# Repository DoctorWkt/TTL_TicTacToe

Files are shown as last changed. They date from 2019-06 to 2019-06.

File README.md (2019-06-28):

# TTL_TicTacToe

I've seen several circuits for two-player tic-tac-toe games on the Internet,
but I thought I'd try to design one with these constraints:

 + done with TTL components only, no CPU
 + minimum number of chips
 + not two player: human versus the board, board makes optimal moves

This is the repository for my result. The circuit uses flip-flops to
register both the human and the board's moves. The board has a register
which holds the current state of the board's moves. The board state and
the user's moves are combined to access a ROM to look up the next board move
and any tie or win result.
An [overview of the design](design_notes.md) is available. Here's
a [video](https://www.youtube.com/watch?v=WPPjL46z-Ag) of the board in action.

There are several versions of the design.

## Logisim Version

I built this [Logisim version](ttt_wkt.circ) in preparation for
designing the real circuit with TTL components. If you haven't used
[Logisim](http://www.cburch.com/logisim/) before, open up the _*.circ_
file. Now start the clock with a control-K (or use
_Simulate -> Ticks Enabled_). Now that the circuit is running, click on
the brown finger icon (the poke tool) at the top-left so that you can
press the game buttons.

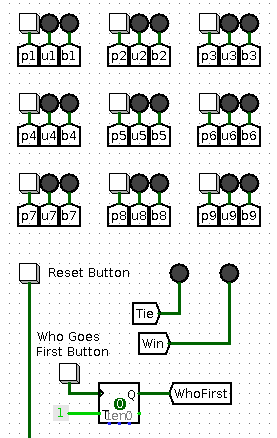
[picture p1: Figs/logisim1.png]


Over on the right you will see a 3x3 grid. The white squares are the
pushbuttons to make a move. Next to each button is a red LED to register
the user's move and a blue LED for the board's moves.

Below this grid there is a Reset button and a "Who Goes First" button.
Press the "Who Goes First" button to toggle between the user moving
first and the board moving first. Then press the Reset button to clear
the board.

Now press the user moves buttons to make your moves. Immediately after
each move, the board will make a move. When a tie occurs, the Tie LED
will light up. When the board wins, the Win LED will light up.

Over on the left are the nine JK flip-flops to record the user's moves,
and the nine JK flip-flops to record the board's moves. Below that is
the ROM which generates a 4-bit value which is the new board's move.
The 4-bit board move goes into the 4:16 demultiplexer to generate the nine
lines which go to the nine JK flip-flops to record the board's moves.
Two of the 16 possible moves are used to indicate a tie or a board win.

The ROM also generates the next state of the board's moves. This is
recorded into a 4-bit register. See the [design notes](design_notes.md)
for details of the state number.

The circuit should come with the latest version of the ROM image. If you
ever regenerate the _ttt.rom_ file, here is how to load it into the circuit.
Right-click on the ROM device in the circuit and choose *Load image* and
choose the _ttl.rom_ file to load.

## Kicad Schematic

In the _Schematic/_ folder you will find a
[Kicad schematic](Schematic/schematic.pdf) for the circuit. This uses:

 + nine 74HC107 dual JK flip flops. Each one holds both the user and board
   move for one position on the board
 + one 28C256 32Kx8 EEPROM to look up the next board move. We only use
   8K of the space in the EEPROM.
 + one 74HC154 4:16 demultiplexer
 + one 75HC161 register to hold the board state number
 + one 555 to generate the clock signal
 + various LEDs to show the moves, and other sundry components.

I've also designed a [PCB](Figs/pcb2.jpg) to hold all the components.
The design has separate LEDs for user and board moves, but I've chosen to use
bi-colour LEDs so that there is a single physical LED for each board position:
green for the user, red for the board, off when empty.

## Generating the 28C256 EEPROM Contents

At the Linux command-line, run the command:

```
make
```

This will use the _gen_moves.pl_ script to generate the user-first moves file
_umoves_, and the board-first moves file _bmoves_. These are then parsed by
the _parse_moves.pl_ script to create the _ttt.rom_ file used by Logisim.

Finally, the _hex2bin_ script takes the _ttt.rom_ file, which is hex-encoded,
and converts it to the binary file _28C256.bin_ which can be burned to the
EEPROM.

If you have a MiniPro EEPROM burner and the _minipro_ command installed,

```
make write
```

will burn the _28C256.bin_ to a 28C256 chip with the MiniPro burner.

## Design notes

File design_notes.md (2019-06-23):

# Design Notes for the TTT Tic Tac Toe Circuit

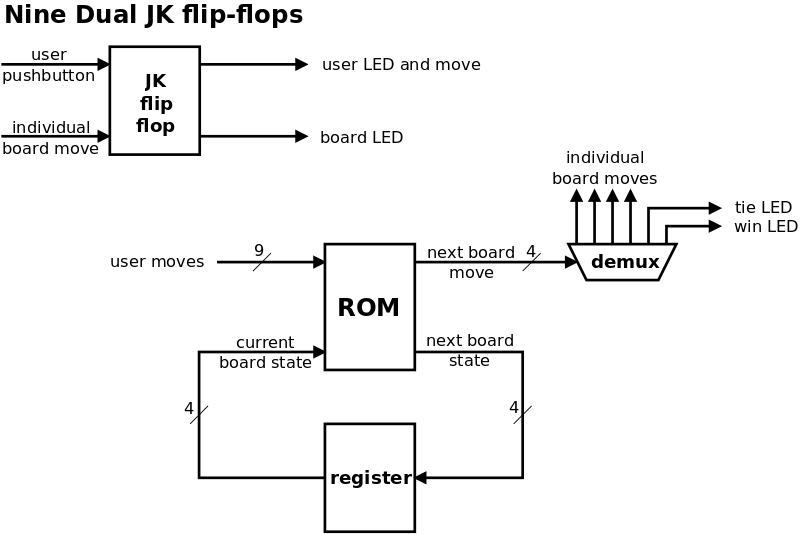
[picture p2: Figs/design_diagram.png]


The state of each position on the board is stored in nine dual JK flip-flops.
The user makes a move by pressing a pushbutton which is recorded in one
flip-flop. Any move made by the board is recorded in a second flip-flop.
This allows two different LEDs to be lit up: green for a user move and red
for a board move at each position. Two flip-flops also allows the board's
move as input to the user flip-flop; this prevents the user from making a
move that the board already has made.

The nine "user move" outputs provide nine bits of address into the ROM.
Four other address bits are provided by a 4-bit register. This records
a "state number" which identifies what set of "board moves" have been
made.

The ROM has 13 bits of input and 8 bits of output. Thus, it can be an 8Kx8
EEPROM. The 13-bit ROM address is used to look up the 8-bit result. Four of the
result bits are the board's next move:

 + 0 means "no move" and is used when waiting for the user to make a move
 + 1 to 9 is a legitimate next move by the board
 + 14 indicates a tie
 + 15 indicates a win by the board

This 4-bit move value goes into the 4:16 demultiplexer to produce the nine
lines that go to the nine flip-flops for the board's move. Two of the
demultiplexer lines, representing 14 and 15, go to the tie LED and board
win LED respectively.

The other four bits of the ROM result are the state number for the new
"board moves". This is recorded into the 4-bit register.

I was originally sending to the ROM nine bits of the user's moves from the user
flip-flops, and  nine bits of the board's moves from the board flip-flops.
This required a ROM with 18 bits of input, i.e. a 256Kx8 ROM. These are not
easily available.

As it turns out, for any 9-bit pattern which is the set of moves that the
user has made, there is only a handful of "board move" situations where
the user could have made this move. Therefore, these situations can be
encoded into a "state number". A state number and the 9-bit "user moves"
pattern is enough to look up the next move the board should play.

There are actually several hundred "board move" situations; I needed
to encode these into 4 bits as I was already outputting 4 bits for the
board's move. Thus, the 4-bit state number is actually a hash value;
several "board move" situations hash down to the same state number.

The constraints on choosing a state number are these:

 + a "board move" situation must always be represented by the same state number
 + any 9-bit "user moves" pattern can be associated with several
   "board move" situations. Each one must be represented with a different
   state number, so as to produce a unique ROM address

Luckily, there are a set of state numbers that satisfy these constraints.
My [parse_moves.pl](parse_moves.pl) script generates these state numbers
and the contents of the ROM.

All of the above has to be implemented with real 7400-style devices.
For the real circuit, I will use these devices:

```
28C256          A 32Kx8 EEPROM, of which we only need 8Kx8. 13 bits of
                input, 8 bits of output. 9 bits of inputs are the user's
                moves so far. 4 bits of input are the current board state
                as stored in the 74HC161 register. 4 output bits represent
                the board move (1 to 9). The other 4 output bits represent
                the next board state to put into the register. A move
                numbered 14 is a tie; a move numbered 15 is a board win.
74HC154         A 4-line to 16-line decoder/demultiplexer, inverting outputs.
                The 4-bit board move output from the ROM is wired to this.
                9 outputs are wired to the flip-flips for the X moves.
74HC161         A 4-bit register to hold the next board state from the EEPROM.
74HC107         Nine dual JK flip-flops with reset; negative-edge trigger.
555             A timer running at 100Hz or so.
```
Finally, there is a switch connected to address line 13 of the 28C256 EEPROM.
This allows the user to move first, or to let the board move first. What is
happening here is that the switch chooses one bank of 8K for the moves and
game state when the user moves first. By toggling the switch, a second
bank of 8K moves are selected for when the board moves first.

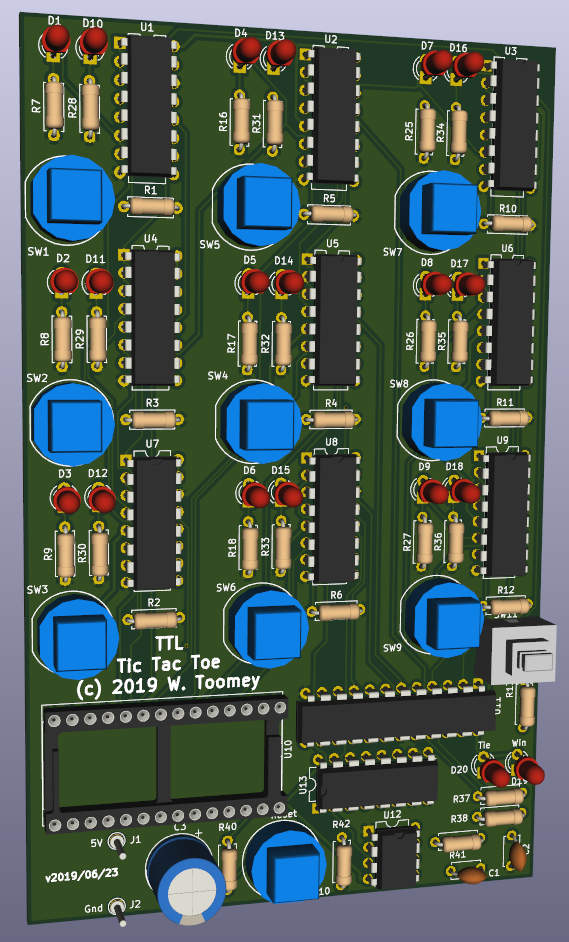
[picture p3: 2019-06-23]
Figs/pcb1.jpg

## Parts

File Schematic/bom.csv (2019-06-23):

Source: | /home/wkt/Schematic/ttt_ttl.sch
Date: | Tue 18 Jun 2019 14:31:49 AEST
Tool: | Eeschema 5.1.2-f72e74a~84~ubuntu18.04.1
Component Count: | 80
Ref | Value | Footprint
C1 | 10nF | Capacitor_THT:C_Disc_D4.7mm_W2.5mm_P5.00mm
C2 | 100nF | Capacitor_THT:C_Disc_D4.7mm_W2.5mm_P5.00mm
C3 | 220uF | Capacitor_THT:CP_Radial_D10.0mm_P2.50mm
D1 | LED | LED_THT:LED_D3.0mm
D2 | LED | LED_THT:LED_D3.0mm
D3 | LED | LED_THT:LED_D3.0mm
D4 | LED | LED_THT:LED_D3.0mm
D5 | LED | LED_THT:LED_D3.0mm
D6 | LED | LED_THT:LED_D3.0mm
D7 | LED | LED_THT:LED_D3.0mm
D8 | LED | LED_THT:LED_D3.0mm
D9 | LED | LED_THT:LED_D3.0mm
D10 | LED | LED_THT:LED_D3.0mm
D11 | LED | LED_THT:LED_D3.0mm
D12 | LED | LED_THT:LED_D3.0mm
D13 | LED | LED_THT:LED_D3.0mm
D14 | LED | LED_THT:LED_D3.0mm
D15 | LED | LED_THT:LED_D3.0mm
D16 | LED | LED_THT:LED_D3.0mm
D17 | LED | LED_THT:LED_D3.0mm
D18 | LED | LED_THT:LED_D3.0mm
D19 | WIN | LED_THT:LED_D3.0mm
D20 | TIE | LED_THT:LED_D3.0mm
J1 | Conn_01x01 | Connector_Pin:Pin_D1.0mm_L10.0mm
J2 | Conn_01x01 | Connector_Pin:Pin_D1.0mm_L10.0mm
R1 | 1K | Resistor_THT:R_Axial_DIN0207_L6.3mm_D2.5mm_P7.62mm_Horizontal
R2 | 1K | Resistor_THT:R_Axial_DIN0207_L6.3mm_D2.5mm_P7.62mm_Horizontal
R3 | 1K | Resistor_THT:R_Axial_DIN0207_L6.3mm_D2.5mm_P7.62mm_Horizontal
R4 | 1K | Resistor_THT:R_Axial_DIN0207_L6.3mm_D2.5mm_P7.62mm_Horizontal
R5 | 1K | Resistor_THT:R_Axial_DIN0207_L6.3mm_D2.5mm_P7.62mm_Horizontal
R6 | 1K | Resistor_THT:R_Axial_DIN0207_L6.3mm_D2.5mm_P7.62mm_Horizontal
R7 | 1K | Resistor_THT:R_Axial_DIN0207_L6.3mm_D2.5mm_P7.62mm_Horizontal
R8 | 1K | Resistor_THT:R_Axial_DIN0207_L6.3mm_D2.5mm_P7.62mm_Horizontal
R9 | 1K | Resistor_THT:R_Axial_DIN0207_L6.3mm_D2.5mm_P7.62mm_Horizontal
R10 | 1K | Resistor_THT:R_Axial_DIN0207_L6.3mm_D2.5mm_P7.62mm_Horizontal
R11 | 1K | Resistor_THT:R_Axial_DIN0207_L6.3mm_D2.5mm_P7.62mm_Horizontal
R12 | 1K | Resistor_THT:R_Axial_DIN0207_L6.3mm_D2.5mm_P7.62mm_Horizontal
R16 | 1K | Resistor_THT:R_Axial_DIN0207_L6.3mm_D2.5mm_P7.62mm_Horizontal
R17 | 1K | Resistor_THT:R_Axial_DIN0207_L6.3mm_D2.5mm_P7.62mm_Horizontal
R18 | 1K | Resistor_THT:R_Axial_DIN0207_L6.3mm_D2.5mm_P7.62mm_Horizontal
R25 | 1K | Resistor_THT:R_Axial_DIN0207_L6.3mm_D2.5mm_P7.62mm_Horizontal
R26 | 1K | Resistor_THT:R_Axial_DIN0207_L6.3mm_D2.5mm_P7.62mm_Horizontal
R27 | 1K | Resistor_THT:R_Axial_DIN0207_L6.3mm_D2.5mm_P7.62mm_Horizontal
R28 | 1K | Resistor_THT:R_Axial_DIN0207_L6.3mm_D2.5mm_P7.62mm_Horizontal
R29 | 1K | Resistor_THT:R_Axial_DIN0207_L6.3mm_D2.5mm_P7.62mm_Horizontal
R30 | 1K | Resistor_THT:R_Axial_DIN0207_L6.3mm_D2.5mm_P7.62mm_Horizontal
R31 | 1K | Resistor_THT:R_Axial_DIN0207_L6.3mm_D2.5mm_P7.62mm_Horizontal
R32 | 1K | Resistor_THT:R_Axial_DIN0207_L6.3mm_D2.5mm_P7.62mm_Horizontal
R33 | 1K | Resistor_THT:R_Axial_DIN0207_L6.3mm_D2.5mm_P7.62mm_Horizontal
R34 | 1K | Resistor_THT:R_Axial_DIN0207_L6.3mm_D2.5mm_P7.62mm_Horizontal
R35 | 1K | Resistor_THT:R_Axial_DIN0207_L6.3mm_D2.5mm_P7.62mm_Horizontal
R36 | 1K | Resistor_THT:R_Axial_DIN0207_L6.3mm_D2.5mm_P7.62mm_Horizontal
R37 | 1K | Resistor_THT:R_Axial_DIN0207_L6.3mm_D2.5mm_P7.62mm_Horizontal
R38 | 1K | Resistor_THT:R_Axial_DIN0207_L6.3mm_D2.5mm_P7.62mm_Horizontal
R40 | 1K | Resistor_THT:R_Axial_DIN0207_L6.3mm_D2.5mm_P7.62mm_Horizontal
R41 | 100K | Resistor_THT:R_Axial_DIN0207_L6.3mm_D2.5mm_P7.62mm_Horizontal
R42 | 20K | Resistor_THT:R_Axial_DIN0207_L6.3mm_D2.5mm_P7.62mm_Horizontal
SW1 | SW_Push | Button_Switch_THT:Push_E-Switch_KS01Q01
SW2 | SW_Push | Button_Switch_THT:Push_E-Switch_KS01Q01
SW3 | SW_Push | Button_Switch_THT:Push_E-Switch_KS01Q01
SW4 | SW_Push | Button_Switch_THT:Push_E-Switch_KS01Q01
SW5 | SW_Push | Button_Switch_THT:Push_E-Switch_KS01Q01
SW6 | SW_Push | Button_Switch_THT:Push_E-Switch_KS01Q01
SW7 | SW_Push | Button_Switch_THT:Push_E-Switch_KS01Q01
SW8 | SW_Push | Button_Switch_THT:Push_E-Switch_KS01Q01
SW9 | SW_Push | Button_Switch_THT:Push_E-Switch_KS01Q01
SW10 | SW_Push | Button_Switch_THT:Push_E-Switch_KS01Q01
SW11 | SW_DPDTx2 | Package_DIP:DIP-6_W7.62mm | TL2230EEF140
U1 | 74HC109 | Package_DIP:DIP-16_W7.62mm
U2 | 74HC109 | Package_DIP:DIP-16_W7.62mm
U3 | 74HC109 | Package_DIP:DIP-16_W7.62mm
U4 | 74HC109 | Package_DIP:DIP-16_W7.62mm
U5 | 74HC109 | Package_DIP:DIP-16_W7.62mm
U6 | 74HC109 | Package_DIP:DIP-16_W7.62mm
U7 | 74HC109 | Package_DIP:DIP-16_W7.62mm
U8 | 74HC109 | Package_DIP:DIP-16_W7.62mm
U9 | 74HC109 | Package_DIP:DIP-16_W7.62mm
U10 | 28C256 | Package_DIP:DIP-28_W15.24mm_Socket
U11 | 74HC154 | Package_DIP:DIP-24_W7.62mm
U12 | NE555 | Package_DIP:DIP-8_W7.62mm
U13 | 74HC161 | Package_DIP:DIP-16_W7.62mm

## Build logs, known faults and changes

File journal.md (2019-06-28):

# Journal for My Tic Tac Toe in TTL Development

Here's my journal for this project. I use it to keep notes and track
my journey. It's probably not that interesting to read.

## Thu  6 Jun 09:43:35 AEST 2019

Yesterday I mused on if a game of Tic Tac Toe could be desgined with
TTL components, and how many chips it would take. After a few hours
I'd designed a working circuit in Logisim and I'd written the scripts
to generate the ROM contents so that the board would always choose the
best next move.

I also chose the ICs that I would use for a real circuit:

```
M27C2001-12F1   erasable, but discontinued. 2MB (256Kx8). 18 bits of input,
                8 bits of output. 4 output bits represent the X move, 1
                output bit is "draw", 1 output bit is "computer wins"
74HC154         4-line to 16-line decoder/demultiplexer, inverting outputs.
                The 4-bit X move output from the ROM is wired to this.
                9 outputs are wired to the flip-flips for the X moves.
74HC107         dual JK flip-flop with reset; negative-edge trigger
555             running at 100Hz or so
```

The [design notes](design_notes.md) have more information about the
overall architecture of the design of the board.

This morning I've sketched out the circuit in Kicad, roughly
arranged the components on a PCB and run freerouter to see how good/bad
the layout is. I've got only 14 or so vias, so that's not too bad.

Now I need to go back and review all the components. Example: the demux
output is active low, so I probably need to wire its outputs to the K
inputs of the J-K flip-flops.

## Thu  6 Jun 11:47:03 AEST 2019

Yes, I had to change to 74HC109 flip-flops as these have a K# input.
Now I use this to register the active-low output from the demux,
and thus I use the Q# output for the active-high registered board moves.
I got rid of some resistors for the push-buttons, and I've laid out the
PCB much more cleanly. Now running freeroute.

## Sun  9 Jun 20:39:17 AEST 2019

I'm trying a design with a smaller ROM because it's easy to get a 32Kx8 ROM
and not easy to get a 256Kx8. In this design, only the human moves go into
the ROM not the board's moves. Instead, there is a 4-bit sequence counter.
Each time the human moves, the sequence counter increments.

The idea is that, after each human move, there is one ideal board move.
So we really only need to know the current sequence number of the moves.
When we get the next human move, the set of moves and the sequence number
should determine the current state, and so we can output the best board
move and increment the sequence counter.

I was worried that I would have some metastability with the counter
and the ROM inputs/outputs, but in Logisim it seems OK. However, I'm
not generating the ROM output correctly. The circuit starts playing OK
but then goes off the rails.

It's likely that we are getting to the same state of human moves
(from several human sequences), and along the way we have chosen
different "best" board moves. And because there are different
board moves along the various paths to the current state, we are
not generating the best next move. So I will have to revisit the
ROM generation code. There is also the worry that this approach
has a gaping logical hole in it which I haven't discovered yet!

## Mon 10 Jun 09:41:06 AEST 2019

Yes a gaping hole because there are several previous states to get to the
current state. So I have an idea with parsing the "moves" file:

 + find all the win and draw states
 + work out the previous state(s) to get to them. Just use one (hopefully)
 + for each state that still hasn't got a previous one, find a previous state
 + repeat until only the empty board has no previous state.

This way, there should be only a single path from any initial move down
to the resulting win or tie.

## Tue 11 Jun 09:36:28 AEST 2019

I tried the above but I still ended up with several hundred states,
so I'd need a 9-bit state register and this would still go into the
ROM, so I'd still need the same size ROM as I had in the beginning.
So I'll give up on this avenue and go back to the original 256Kx8 ROM.

I've redone the Logisim circuit with the LEDs and buttons in a 3x3
grid at the top-right of the circuit.

## Wed 12 Jun 06:22:49 AEST 2019

Yesterday I got to Jaycar and bought the flip-flops, mux, LEDs and
resistors. Last night I started with one flip-flop and got it so it
would record a user move, a board move and stop a user changing a
board move. I've wired up three flip-flops so far:

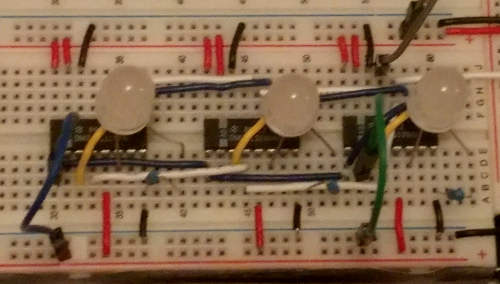
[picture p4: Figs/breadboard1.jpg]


I can't find the small pushbuttons that I know I've got somewhere.
What's concerning is that the pinout of the 74LS109 in Kicad doesn't
match the actual chip. Example: left-hand J and K# are pins 2 and 3
but Kicad has them as pins 1 and 9. I'll have to redo the pinout.
I've also ordered two M27C2001 ROMs from utsource. Until they arrive
I can either use one of the 28C256 32Kx8 EEPROMs that I have (only 15
bits or addressing), or dig out my spare 27C322 2Mx16 EPROM which I
used as the ALU in the CSCvon8. That takes 10 minutes to program
though.

I've updated the schematic with the proper pinouts for the 74LS109.
I've added a couple of pads for power input and a 220uF cap as well.
The 74LS109 was a DIP-14 and now a DIP-16, hah!! Anyway, I'm running
a freeroute just to see how many vias are required. Looks like about
8 vias which is pretty good. I've added the copper zones and done a
DRC and all is OK.

## Thu 13 Jun 09:23:27 AEST 2019

I just had an idea a few minutes ago. The nine bits of user move into
the ROM are a given. But for this "state" of user moves, how many
possible X move combinations are there? If there's only a few, we can
store them in a register, and then update the register to move us to
the next "X state". We already have the flip-flops recording the
"O state". And if by few, I mean 6 or less, then we can use a 9+6=15 bit
EEPROM instead of a large EEPROM. We will need one more chip.

I've written the Perl code to evaluate, and the biggest "X state" space
for any "O state" is six. This fits nicely into three bits. We can use
3 bits of a 4-bit register and feed 9+3 bits into the EEPROM.

The problem is, we need 3 bits of output to update the "X state" register.
We already need 4 bits of output for the next X move. There's only one
bit left over if the EEPROM has 8 bits of output, so how do we indicate
both a win and a tie?

I think I know the answer. It will take two clock cycles. On the first cycle,
the user enters a move and updates the "O state". The current "X state" is
known. We look up in the ROM the next X move and the next "X state". This gets
stored in the register.

On the second cycle, the "O state" is the same but the "X state" is new.
Now, we output the same "X state" but we output a number 14 as the X move
H for a tie, and number 15 as the X move for a win. These go to the demux
and we tie the LEDs to outputs 14 and 15.

I'll use a 161 as a register as I should already have them at home.

Um, well. The problem is yes there are only a few X state to go
with each O state. But I've got to derive state numbers so that previous
states can point to them. But. Assume that there are only 4-bit state
numbers, so there's only 16 possible state numbers. There are 185 actual
X states, so I'm going to have to re-use state numbers across the X states.
To do this, I have to ensure that there won't be a collision between
a shared X state number and a valid O state at that point. Now how do I
do that?

Effectively, I have a matrix of Ostates and Xstates:

```
       Xstate |
Ostate        | XX______X  XX__X___X  XX__X____  etc
--------------+--------------------------------------------------------
  __OO__OO_   |
  ___O_____   |
  O__OO__O_   |
     etc      |
```

and in the middle I need to generate state numbers but in such a way
that in each column the state number is constant but on each row
every state number is different. Is this even possible?

## Thu 13 Jun 14:12:01 AEST 2019

I've just spent way too long on this. I had to write a recursive solution
to allocate the state numbers. It's sort of working but not always working.
So something is wrong, not sure what yet.

## Sun 16 Jun 12:18:15 AEST 2019

At home. I've written a Perl program to load the ROM and play the game using
the ROM. It plays the same way as the Logisim version, so at least there is
consistency.

Hah. I added code to parse_moves.pl when I was writing to a ROM value that
was already there, and I'm doing this a lot. That means my state values are
not what they should be. Added some more debug code and I can see several
Ostates with Xstates that have the same state number.

I decided to rewrite the recursive algorithm from scratch. I still see
some warning flags but both the Logisim and Perl versions seem to be
working as far as I've been able to test them.

I've redone the schematic and PCB with the 74HC161, moved the power
pins to align with my micro-USB connectors, and done the copper pour.
129.5mm by 80mm.

## Mon 17 Jun 09:23:24 AEST 2019

I announced the project on Twitter, and I've just improved the design notes
with a discussion of the state numbers.

## Tue 18 Jun 10:53:11 AEST 2019

I bought some pushbuttons at Jaycar but they are bigger than the ones I'd
put on the PCB design. So last night I redid the PCB design. It also means
that I'll have to do some rewiring of my breadboard version as I will need
to make some room for the switches.

Also, I realised that I'll have to redo the wiring for the win and tie LEDs.
I forgot that the demux is active low, so it drops to zero when a line is
active. I'll have to use the demux outputs as "ground" and wire the LEDs
up to Vcc, i.e. backwards in a sense.

## Wed 19 Jun 10:44:02 AEST 2019

Last night I moved the flip-flop chips on the breadboard to accomodate the
pushbuttons. I was able to get five of the flip-flops wired up:

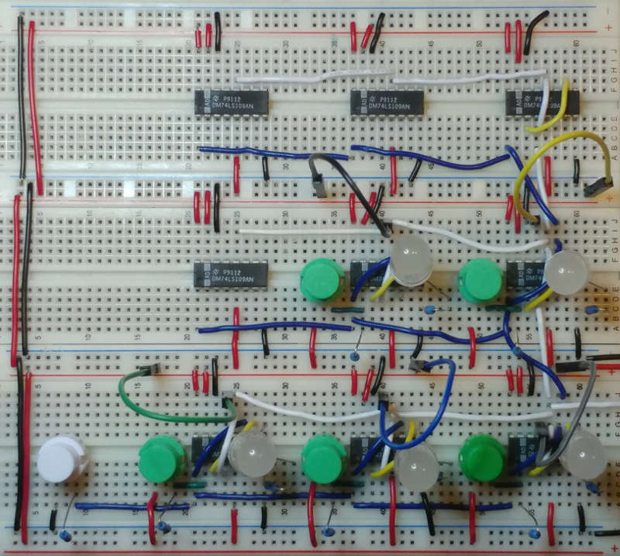
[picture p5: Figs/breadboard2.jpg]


The white button is the reset button, the green buttons are the user
move buttons. There are five patch cables to hold the board move
high, but I can toggle them to make a board move. Eventually the
patch cables will go away when the nine demux lines are connected
to the nine flip-flop chips.

## Thu 20 Jun 09:40:17 AEST 2019

I've wired up all the remaining flip-flops as above. The last five have
very dim LEDs, but they work as expected. I can't tell if this is the
LEDs, the chips or what. I swapped a pair of LEDs and that didn't make
a difference. So it's either the wiring, the resistor or the chip.

Ah, it's the resistors. Some are 1K (too much) and others are 100ohm.
I might experiment with some which are as close to 1K as I can get
to ensure we don't drop the voltage too much.

I've put in the 4:16 demux and tested it in isolation with some jumpers
and a LED. Now I've wired in the nine lines out to the flip-flops and
checked, with the jumpers, that these work fine. Now it's time for the
ROM and register!

I've put them both on the breadboard. I've wired the register inputs and
outputs to the ROM. I've added the reset and clock lines to the register.
I've wired the four move lines from the ROM to the demux. I think all that's
left are the nine user moves to the ROM, oh, and the debugging! Lunch time.

## Thu 20 Jun 13:27:53 AEST 2019

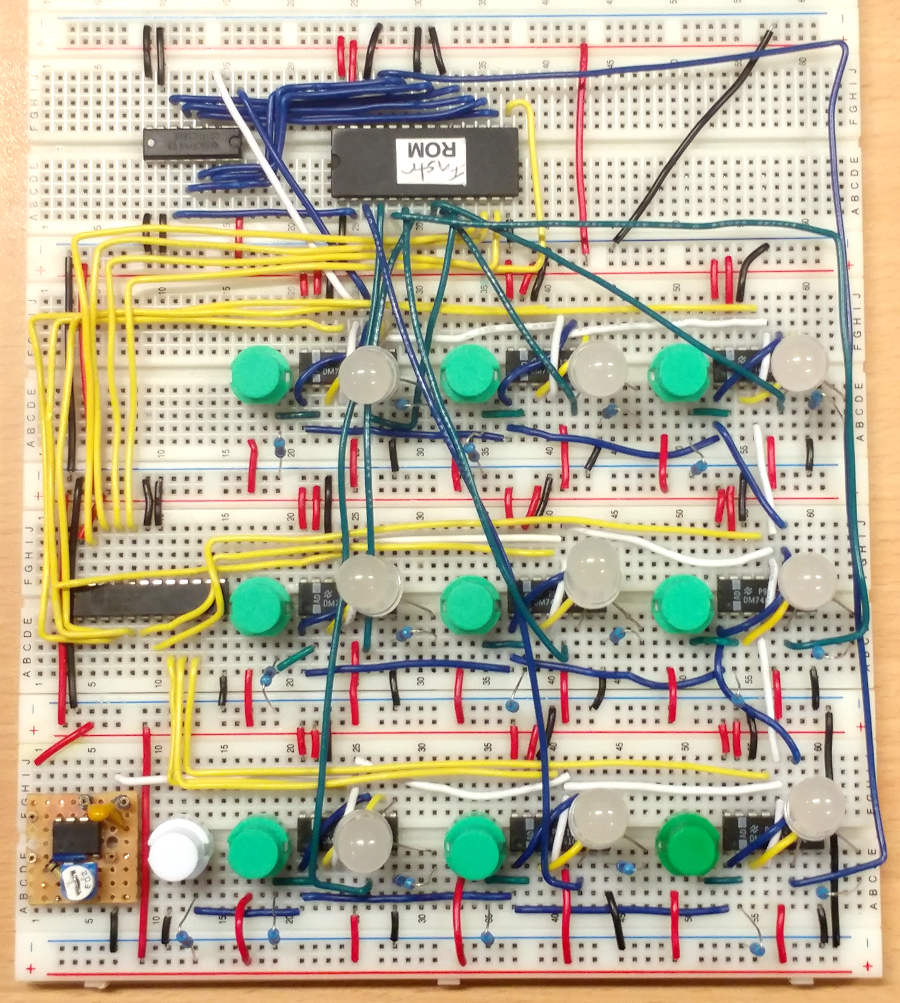
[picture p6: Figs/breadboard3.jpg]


I've done the wiring. Position 1 is top-left, position 9 is bottom-right.
White lines are the clock, blue is reset. The yellow lines are the select
lines into the demux and the board move lines out from the demux. The blue
lines on the register are the lines in from the ROM and the lines out to the
ROM. The green lines are the user move lines in as address lines for the ROM.
Yes, I ran out of green wire for two of the user move lines.

Well, it sort of works. After a reset, the board has already moved at
position 1. I can then make some moves, and it generally plays sensible
moves to block me and/or build a winning line. A reset brings it back to
the current start situation.

Thus there is some debugging to do. Why are we starting with the board
moving at position 1? I think once that's fixed then perhaps the other
move oddities will go away. I have a single LED/resistor with me and
I've just checked that both the win and tie LEDs light up with the
0V values from the demux. That's excellent news.

## Thu 20 Jun 13:51:21 AEST 2019

I found it. The user move wire for position 5 was wired to the wrong
pin on the flip-flop. It's fixed. Now a reset keeps all positions off,
and the board seems to be playing a sensible game. Later, I'll fix up
the LED resistors and put in a green tie LED as well as the red win LED. Then
I'll do a [video for Youtube](https://www.youtube.com/watch?v=WPPjL46z-Ag).
Success!

## Sun 23 Jun 08:21:11 AEST 2019

I was watching some of Robert Barusch's videos and he mentioned
https://jlcpcb.com/, and they are much cheaper than breadboardkillers,
so I've also ordered 5 PCBs from them. On hackaday.io, Ken Yap suggested
a way to allow the board to move first. I've done it a slightly different
way. Use another 8K of ROM to hold the moves and states for when the
board moves in position 1 first. Use a switch and a pull-down resistor
to set the ROM's A13 line to low for user-first, high for board-first.
I've just modified gen_moves.pl and parse_moves.pl to create multiple
moves and ROM files. I've loaded the new ROM into the existing Logisim
version and it works fine. I might try it out on the breadboard version
with an actual switch.

I added the switch and resistor to the breadboard, also to the PCB design.
Now 7 vias, sigh. There was a couple of small bugs in the Perl code which
I fixed, and now the breadboard can play board first and shows the wins
and ties. All good. Now to update the documentation.

## Thu 27 Jun 10:12:59 AEST 2019

The PCBs that I ordered from JLCPCB arrived yesterday. I was able to
spend a couple of hours taking the components from the breadboard and
soldering them to the PCB. There were no wiring problems. The only main
problem was that my bi-colour LEDs are much larger than the two separate LEDs;
they actually bump into the pushbuttons. Also, the buttons for one
row are closer to the LEDs for the row below. If I redesigned the board,
I would move the buttons to be right next to the LEDs, and I'd make room
for 10mm bi-colour LEDs.

Apart from this, it all went well. The little micro USB daughter board 
works fine to supply power, and the board worked once I got all the chips on it.
I haven't done the user/board first switch yet; I'll do
that soon. So this is the second PCB that I've ordered and I'm still
surprised that I can design a PCB and it just works :-)

## Sat 29 Jun 09:16:11 AEST 2019

I got time to add the switch and resistor for the user/board first selection.
Here's a photo of the final PCB:

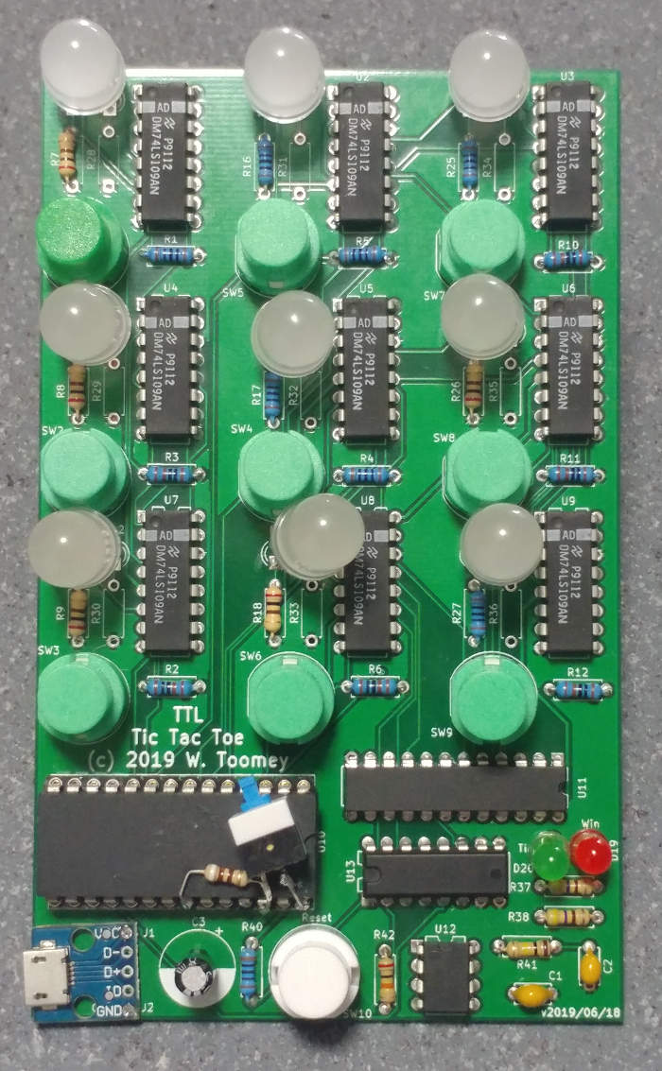
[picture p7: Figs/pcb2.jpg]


And that's the end of the project. Not bad for nine flip-flops, a 16Kx8 ROM,
a register and a 4:16 demux!

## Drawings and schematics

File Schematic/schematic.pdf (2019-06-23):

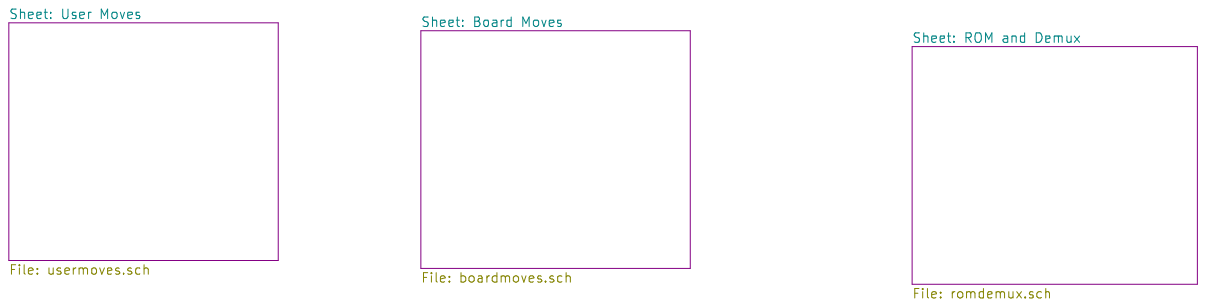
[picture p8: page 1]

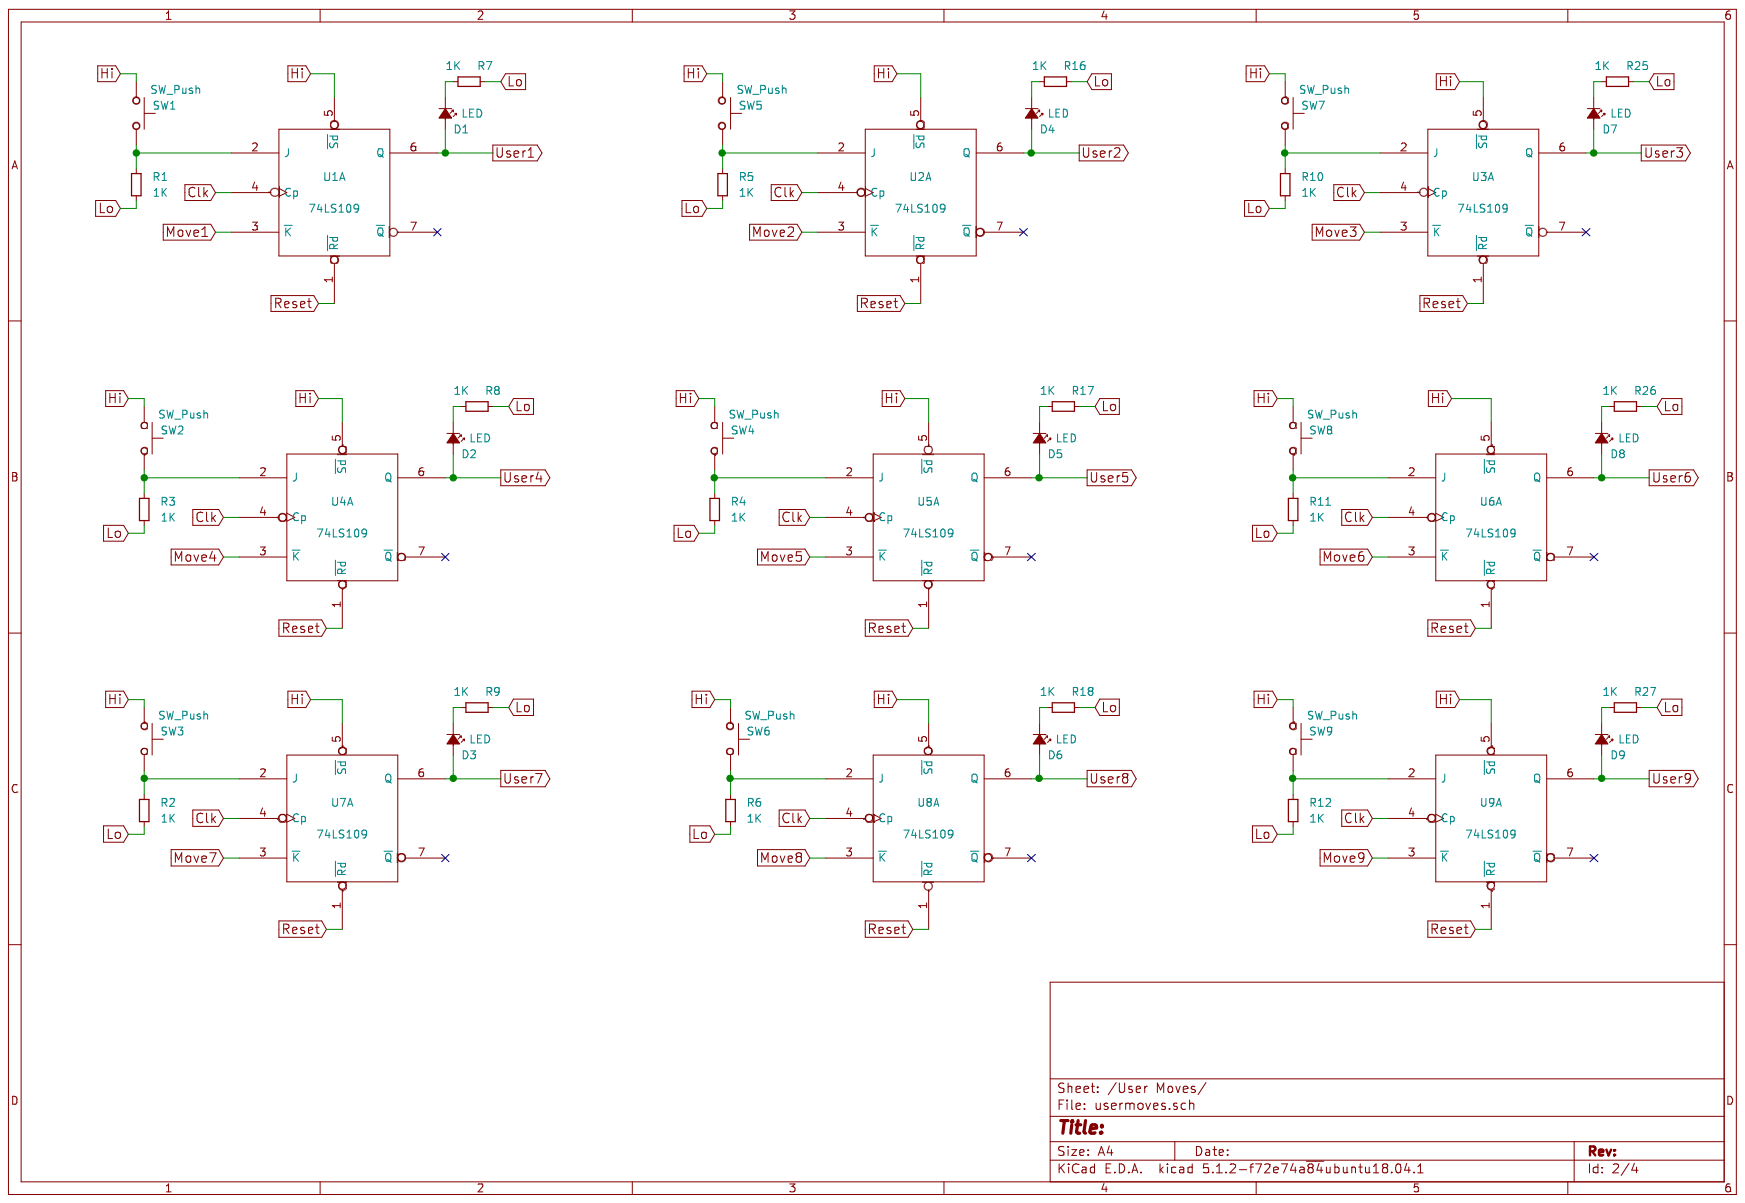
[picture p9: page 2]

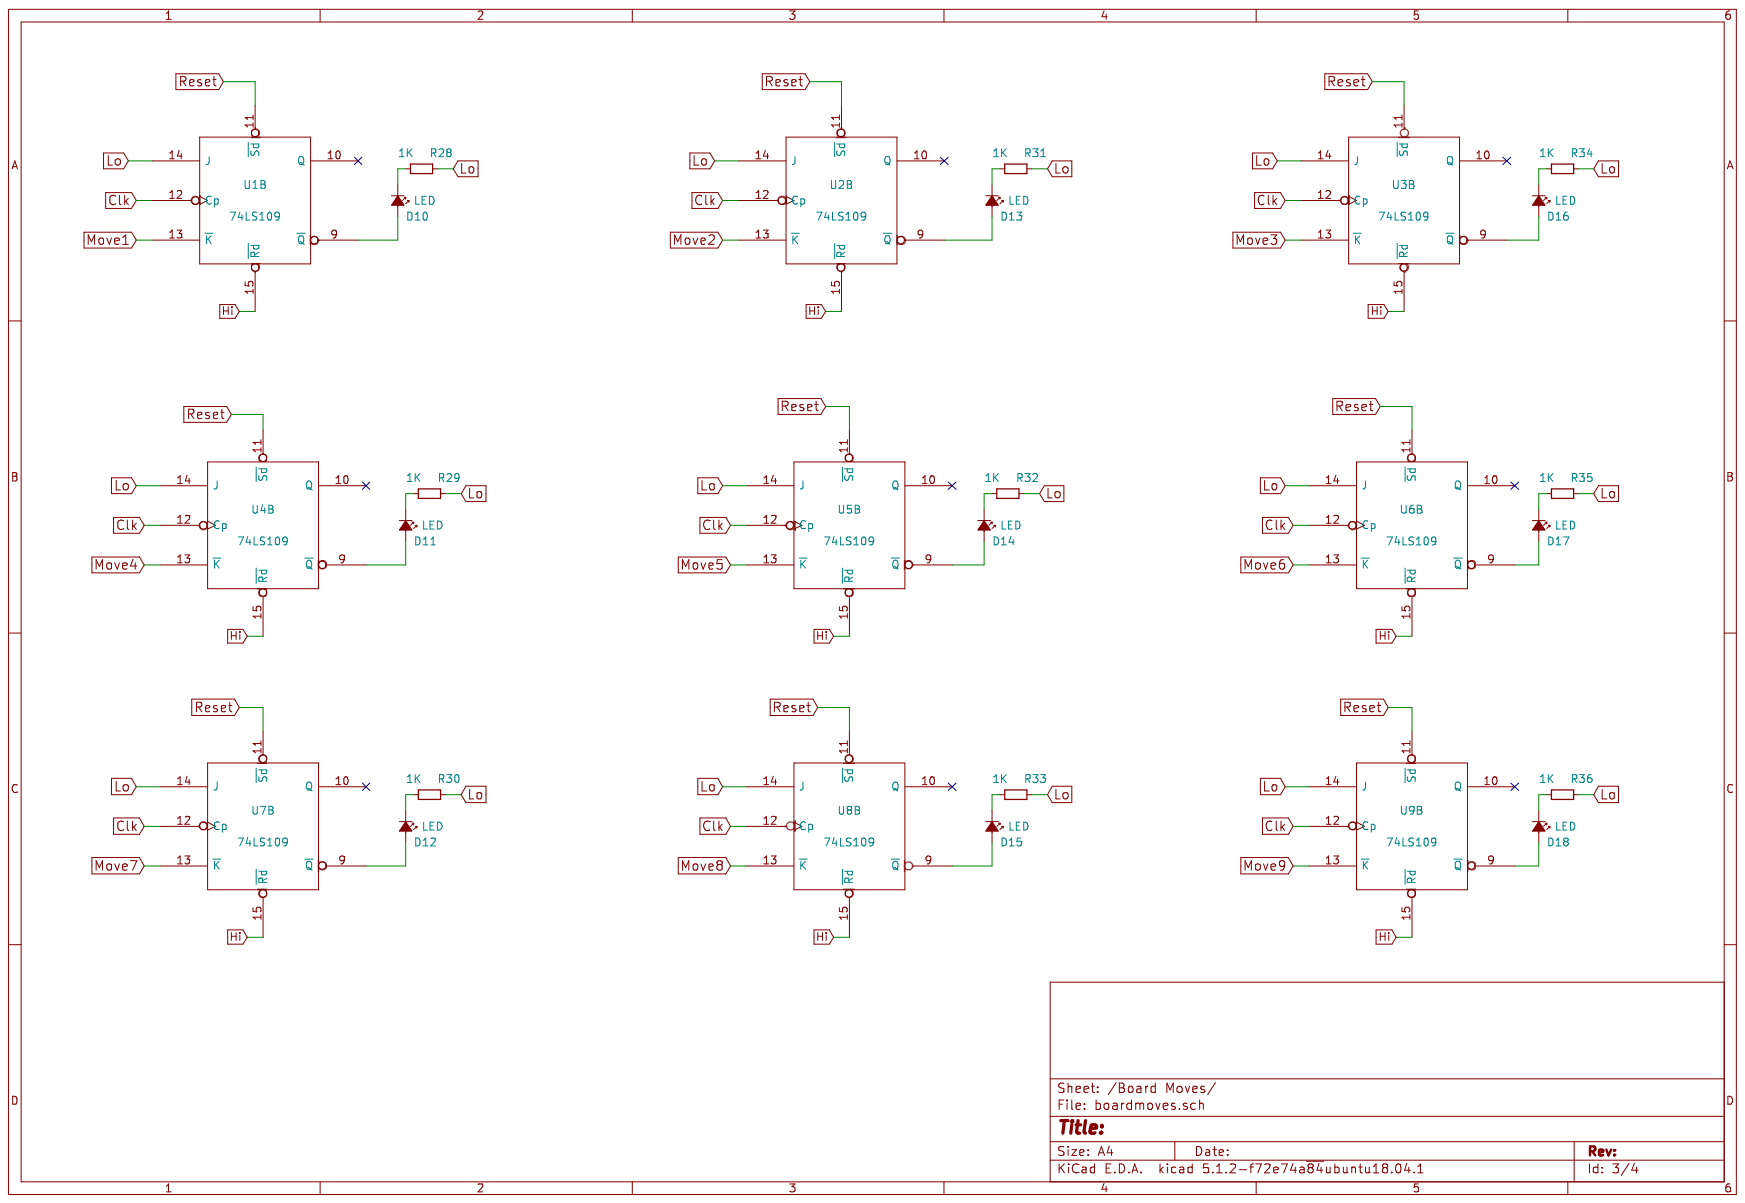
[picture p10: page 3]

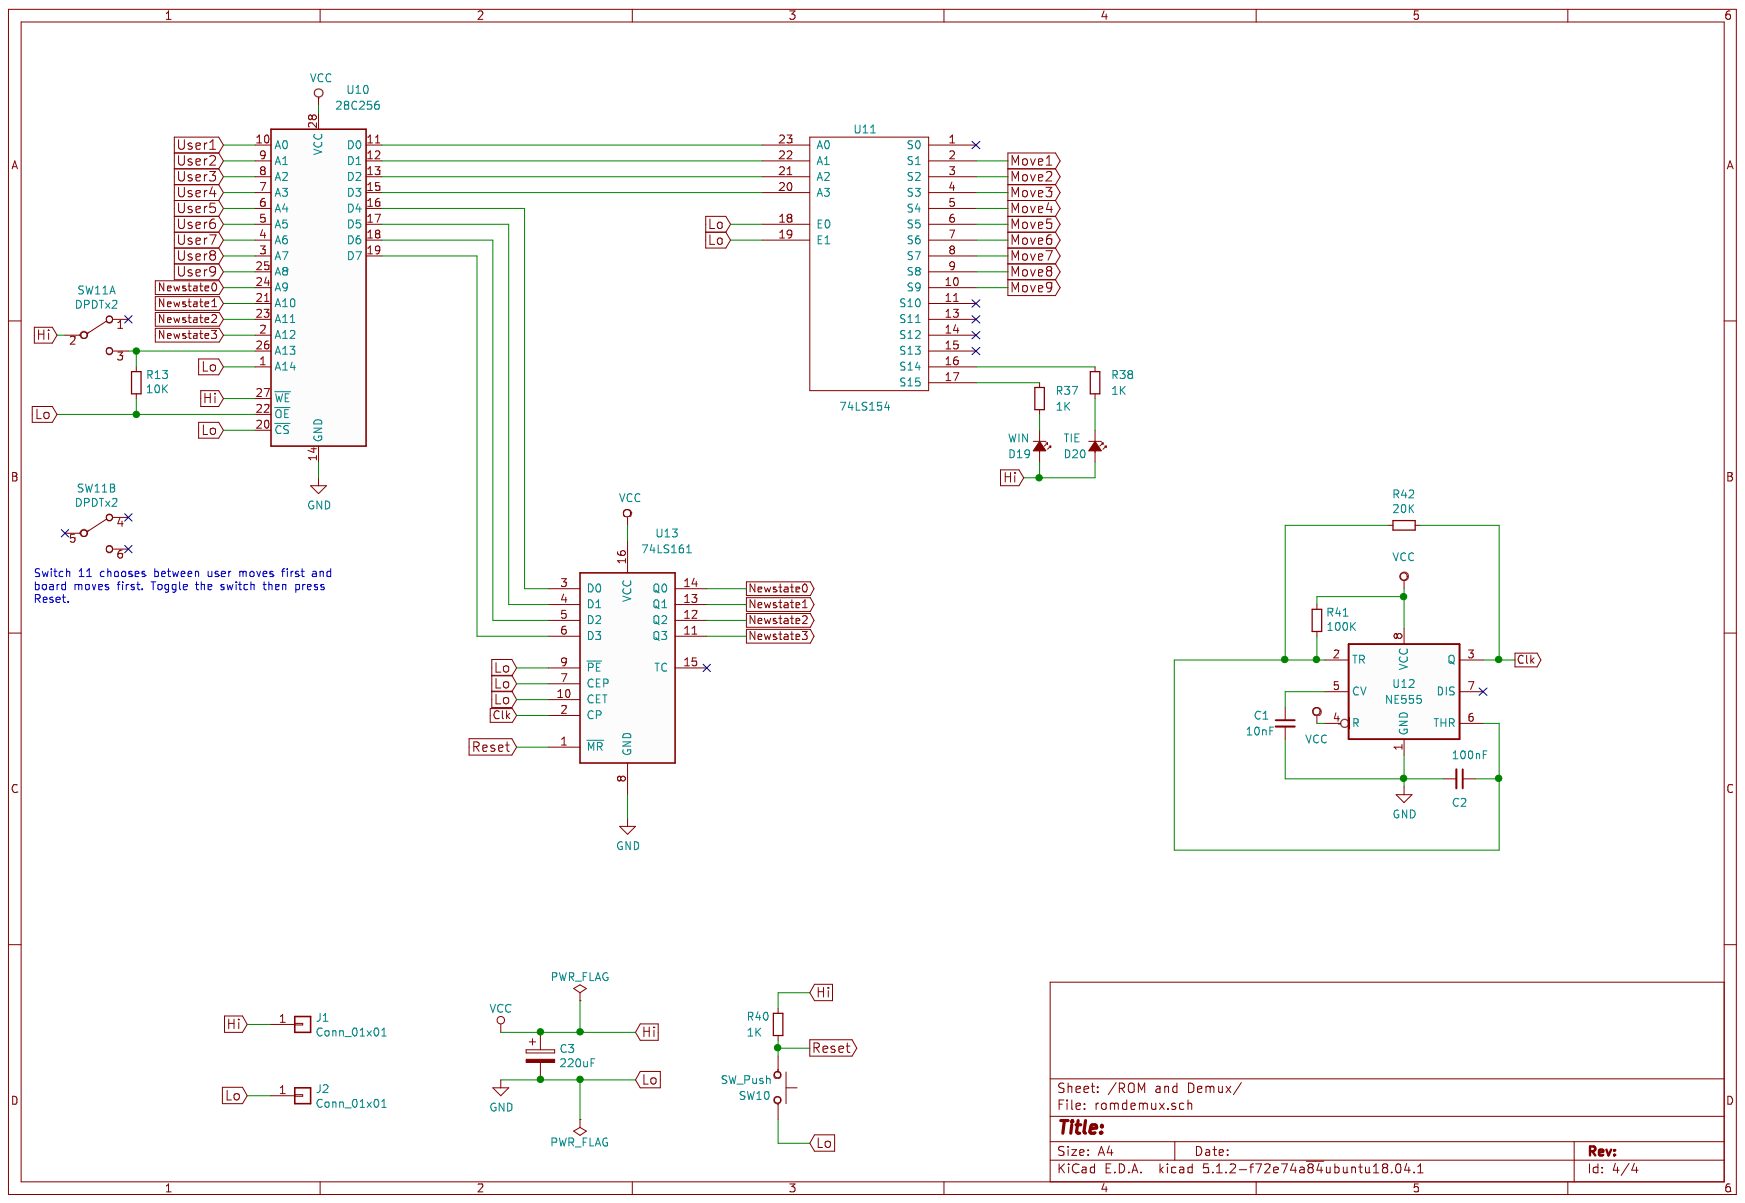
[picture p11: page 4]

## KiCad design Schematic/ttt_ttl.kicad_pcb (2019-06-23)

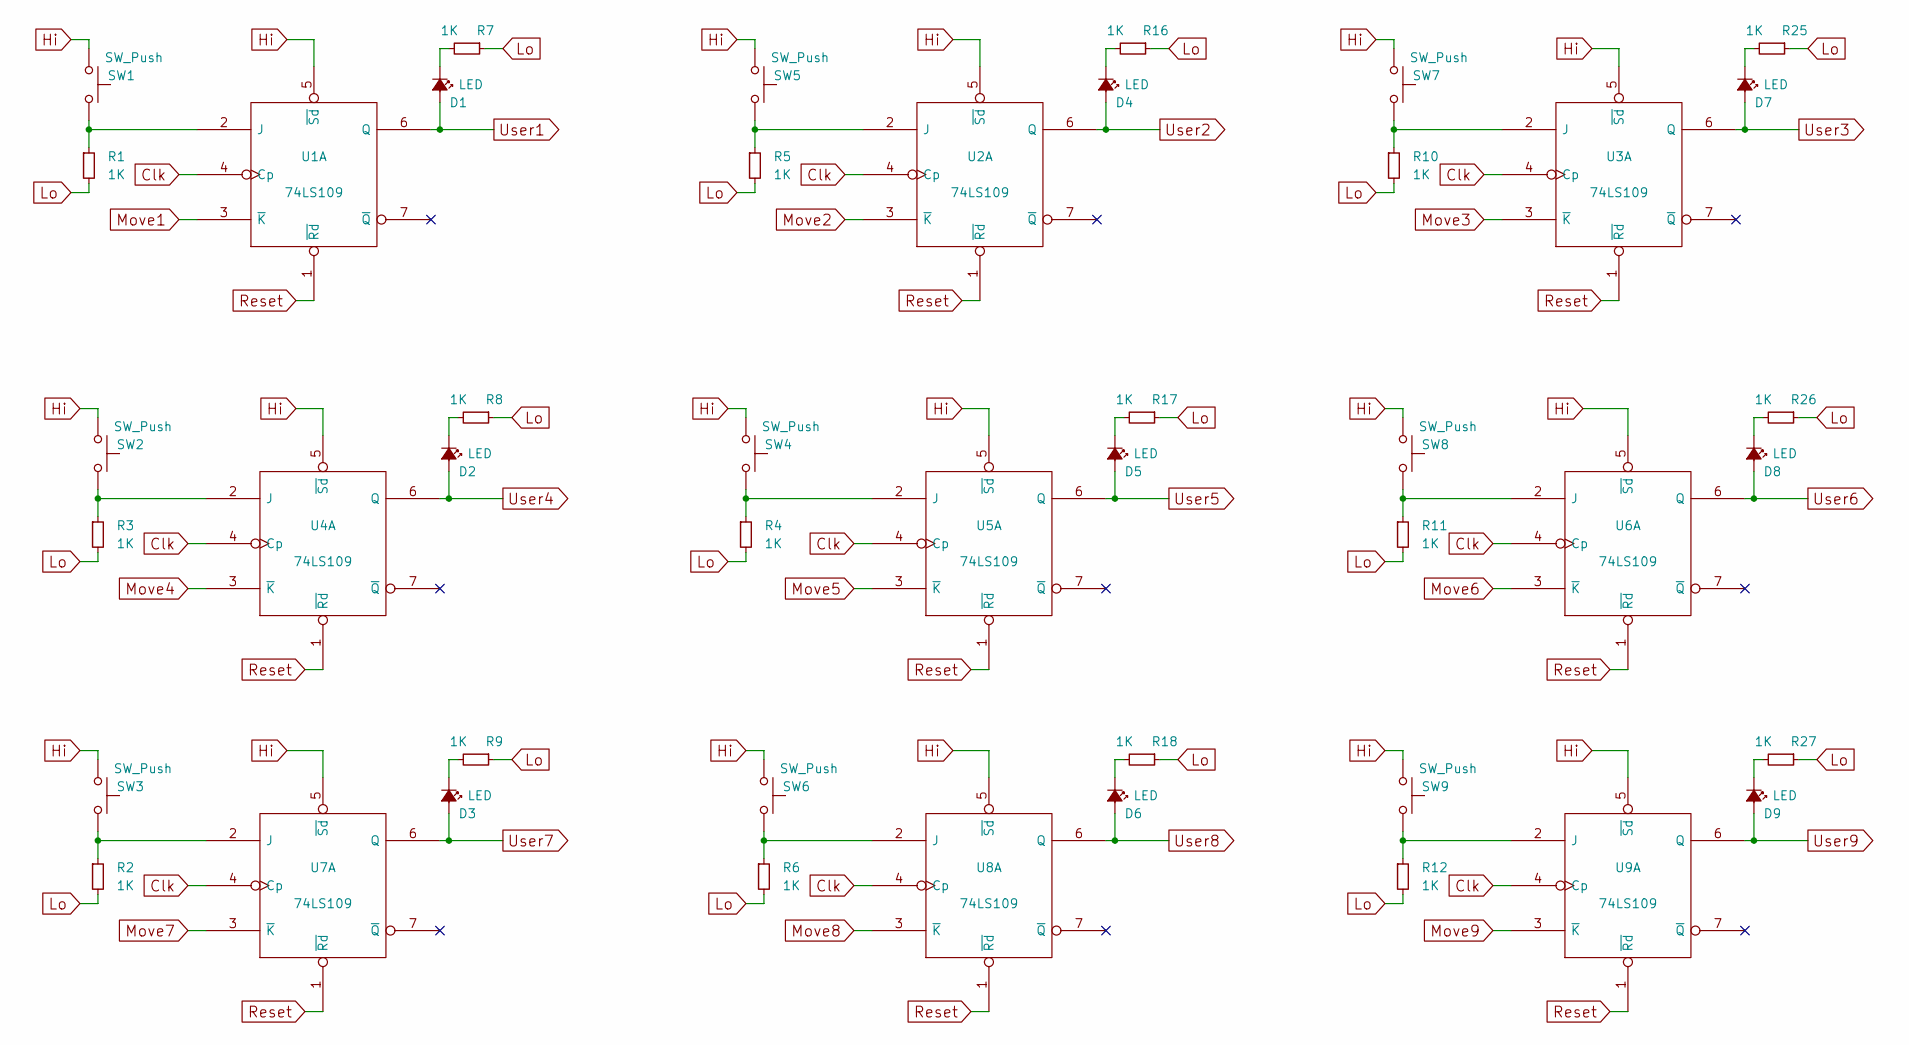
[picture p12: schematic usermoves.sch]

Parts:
D1, D2, D3, D4, D5, D6, D7, D8, D9: LED; LED_D3.0mm
R1, R2, R3, R4, R5, R6, R7, R8, R9, R10, R11, R12, R16, R17, R18, R25, R26, R27: 1K; R_Axial_DIN0207_L6.3mm_D2.5mm_P7.62mm_Horizontal
SW1, SW2, SW3, SW4, SW5, SW6, SW7, SW8, SW9: SW_Push; Push_E-Switch_KS01Q01
U1, U2, U3, U4, U5, U6, U7, U8, U9: 74LS109; DIP-16_W7.62mm

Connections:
Clk: U1.4 (Cp), U2.4 (Cp), U3.4 (Cp), U4.4 (Cp), U5.4 (Cp), U6.4 (Cp), U7.4 (Cp), U8.4 (Cp), U9.4 (Cp); also elsewhere on the board
Hi: SW1.1, SW2.1, SW3.1, SW4.1, SW5.1, SW6.1, SW7.1, SW8.1, SW9.1, U1.5 (~Sd), U1.16 (VCC), U2.5 (~Sd), U2.16 (VCC), U3.5 (~Sd), U3.16 (VCC), U4.5 (~Sd), U4.16 (VCC), U5.5 (~Sd), U5.16 (VCC), U6.5 (~Sd), U6.16 (VCC), U7.5 (~Sd), U7.16 (VCC), U8.5 (~Sd), U8.16 (VCC), U9.5 (~Sd), U9.16 (VCC); also elsewhere on the board
Lo: R1.2, R2.2, R3.2, R4.2, R5.2, R6.2, R7.1, R8.1, R9.1, R10.2, R11.2, R12.2, R16.1, R17.1, R18.1, R25.1, R26.1, R27.1, U1.8 (GND), U2.8 (GND), U3.8 (GND), U4.8 (GND), U5.8 (GND), U6.8 (GND), U7.8 (GND), U8.8 (GND), U9.8 (GND); also elsewhere on the board
Move1: U1.3 (~K); also elsewhere on the board
Move2: U2.3 (~K); also elsewhere on the board
Move3: U3.3 (~K); also elsewhere on the board
Move4: U4.3 (~K); also elsewhere on the board
Move5: U5.3 (~K); also elsewhere on the board
Move6: U6.3 (~K); also elsewhere on the board
Move7: U7.3 (~K); also elsewhere on the board
Move8: U8.3 (~K); also elsewhere on the board
Move9: U9.3 (~K); also elsewhere on the board
unnamed: D1.1 (K), R7.2
unnamed: D2.1 (K), R8.2
unnamed: D3.1 (K), R9.2
unnamed: D4.1 (K), R16.2
unnamed: D5.1 (K), R17.2
unnamed: D6.1 (K), R18.2
unnamed: D7.1 (K), R25.2
unnamed: D8.1 (K), R26.2
unnamed: D9.1 (K), R27.2
unnamed: R1.1, SW1.2, U1.2 (J)
unnamed: R2.1, SW3.2, U7.2 (J)
unnamed: R3.1, SW2.2, U4.2 (J)
unnamed: R4.1, SW4.2, U5.2 (J)
unnamed: R5.1, SW5.2, U2.2 (J)
unnamed: R6.1, SW6.2, U8.2 (J)
unnamed: R10.1, SW7.2, U3.2 (J)
unnamed: R11.1, SW8.2, U6.2 (J)
unnamed: R12.1, SW9.2, U9.2 (J)
Reset: U1.1 (~Rd), U2.1 (~Rd), U3.1 (~Rd), U4.1 (~Rd), U5.1 (~Rd), U6.1 (~Rd), U7.1 (~Rd), U8.1 (~Rd), U9.1 (~Rd); also elsewhere on the board
User1: D1.2 (A), U1.6 (Q); also elsewhere on the board
User2: D4.2 (A), U2.6 (Q); also elsewhere on the board
User3: D7.2 (A), U3.6 (Q); also elsewhere on the board
User4: D2.2 (A), U4.6 (Q); also elsewhere on the board
User5: D5.2 (A), U5.6 (Q); also elsewhere on the board
User6: D8.2 (A), U6.6 (Q); also elsewhere on the board
User7: D3.2 (A), U7.6 (Q); also elsewhere on the board
User8: D6.2 (A), U8.6 (Q); also elsewhere on the board
User9: D9.2 (A), U9.6 (Q); also elsewhere on the board

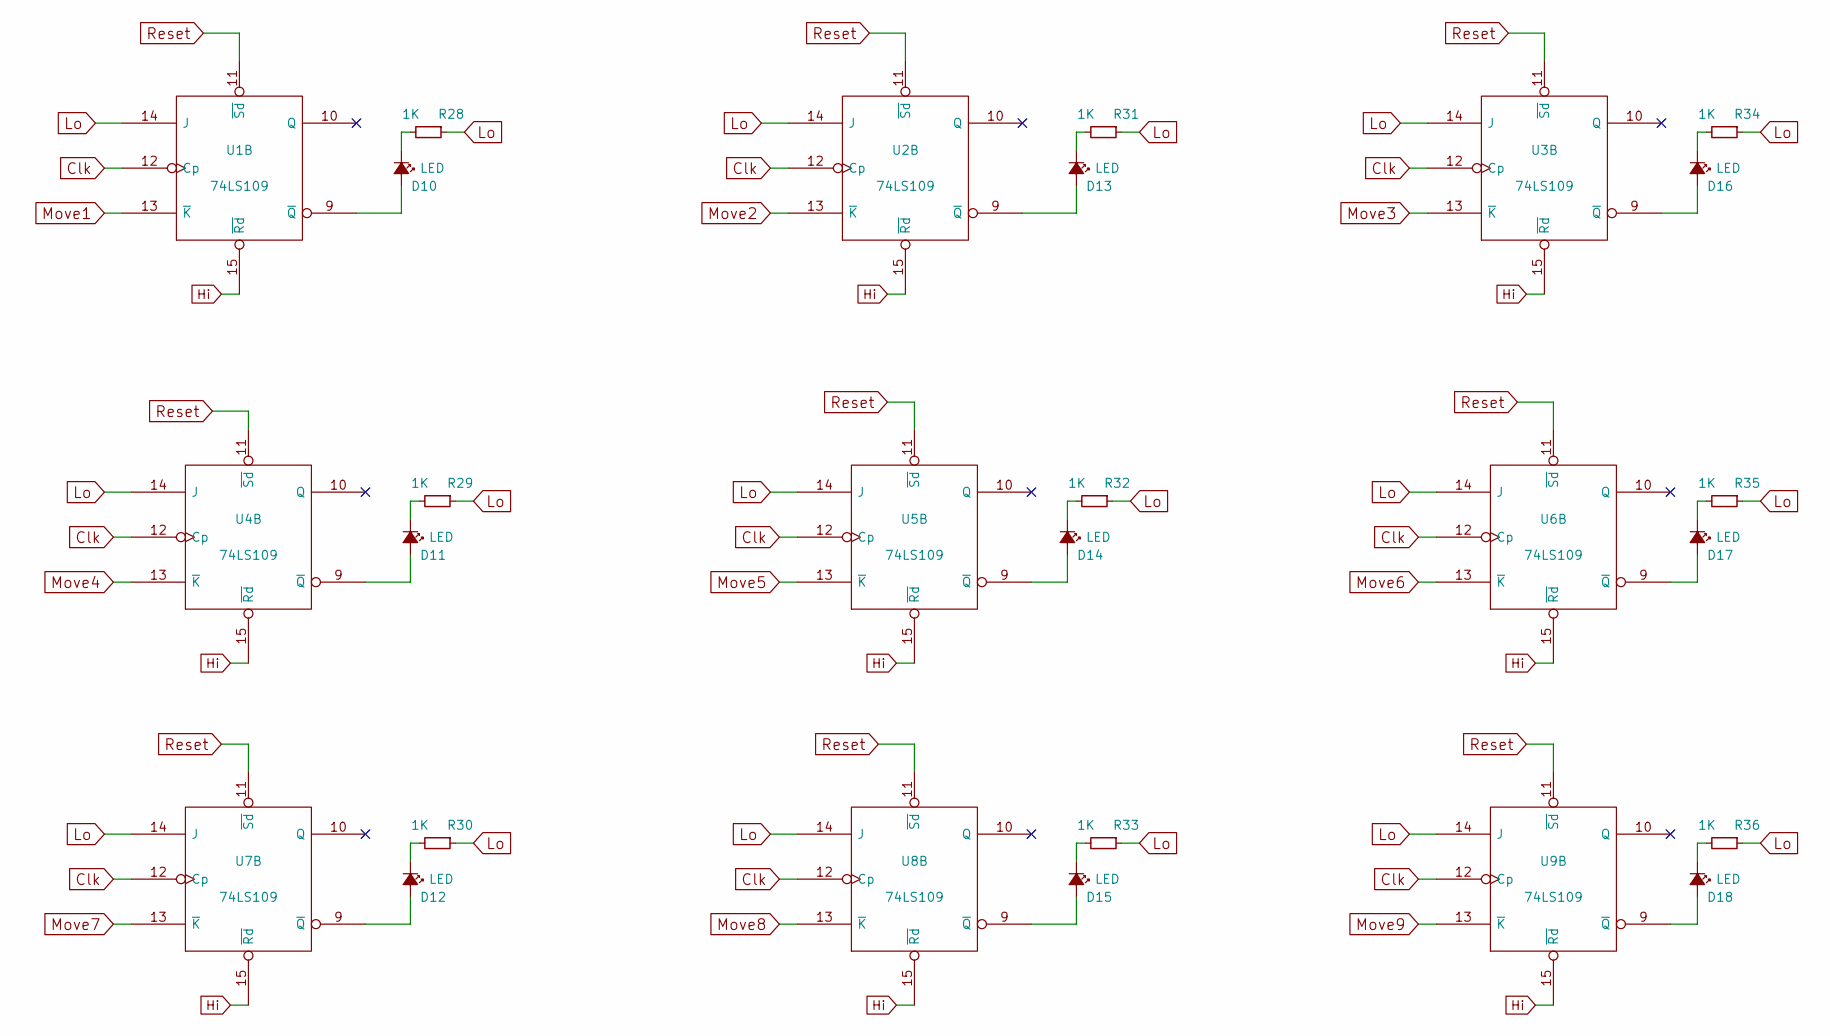
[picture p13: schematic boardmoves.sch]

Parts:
D10, D11, D12, D13, D14, D15, D16, D17, D18: LED; LED_D3.0mm
R28, R29, R30, R31, R32, R33, R34, R35, R36: 1K; R_Axial_DIN0207_L6.3mm_D2.5mm_P7.62mm_Horizontal
U1, U2, U3, U4, U5, U6, U7, U8, U9: 74LS109; DIP-16_W7.62mm

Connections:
Clk: U1.12 (Cp), U2.12 (Cp), U3.12 (Cp), U4.12 (Cp), U5.12 (Cp), U6.12 (Cp), U7.12 (Cp), U8.12 (Cp), U9.12 (Cp); also elsewhere on the board
Hi: U1.15 (~Rd), U1.16 (VCC), U2.15 (~Rd), U2.16 (VCC), U3.15 (~Rd), U3.16 (VCC), U4.15 (~Rd), U4.16 (VCC), U5.15 (~Rd), U5.16 (VCC), U6.15 (~Rd), U6.16 (VCC), U7.15 (~Rd), U7.16 (VCC), U8.15 (~Rd), U8.16 (VCC), U9.15 (~Rd), U9.16 (VCC); also elsewhere on the board
Lo: R28.1, R29.1, R30.1, R31.1, R32.1, R33.1, R34.1, R35.1, R36.1, U1.8 (GND), U1.14 (J), U2.8 (GND), U2.14 (J), U3.8 (GND), U3.14 (J), U4.8 (GND), U4.14 (J), U5.8 (GND), U5.14 (J), U6.8 (GND), U6.14 (J), U7.8 (GND), U7.14 (J), U8.8 (GND), U8.14 (J), U9.8 (GND), U9.14 (J); also elsewhere on the board
Move1: U1.13 (~K); also elsewhere on the board
Move2: U2.13 (~K); also elsewhere on the board
Move3: U3.13 (~K); also elsewhere on the board
Move4: U4.13 (~K); also elsewhere on the board
Move5: U5.13 (~K); also elsewhere on the board
Move6: U6.13 (~K); also elsewhere on the board
Move7: U7.13 (~K); also elsewhere on the board
Move8: U8.13 (~K); also elsewhere on the board
Move9: U9.13 (~K); also elsewhere on the board
unnamed: D10.1 (K), R28.2
unnamed: D10.2 (A), U1.9 (~Q)
unnamed: D11.1 (K), R29.2
unnamed: D11.2 (A), U4.9 (~Q)
unnamed: D12.1 (K), R30.2
unnamed: D12.2 (A), U7.9 (~Q)
unnamed: D13.1 (K), R31.2
unnamed: D13.2 (A), U2.9 (~Q)
unnamed: D14.1 (K), R32.2
unnamed: D14.2 (A), U5.9 (~Q)
unnamed: D15.1 (K), R33.2
unnamed: D15.2 (A), U8.9 (~Q)
unnamed: D16.1 (K), R34.2
unnamed: D16.2 (A), U3.9 (~Q)
unnamed: D17.1 (K), R35.2
unnamed: D17.2 (A), U6.9 (~Q)
unnamed: D18.1 (K), R36.2
unnamed: D18.2 (A), U9.9 (~Q)
Reset: U1.11 (~Sd), U2.11 (~Sd), U3.11 (~Sd), U4.11 (~Sd), U5.11 (~Sd), U6.11 (~Sd), U7.11 (~Sd), U8.11 (~Sd), U9.11 (~Sd); also elsewhere on the board

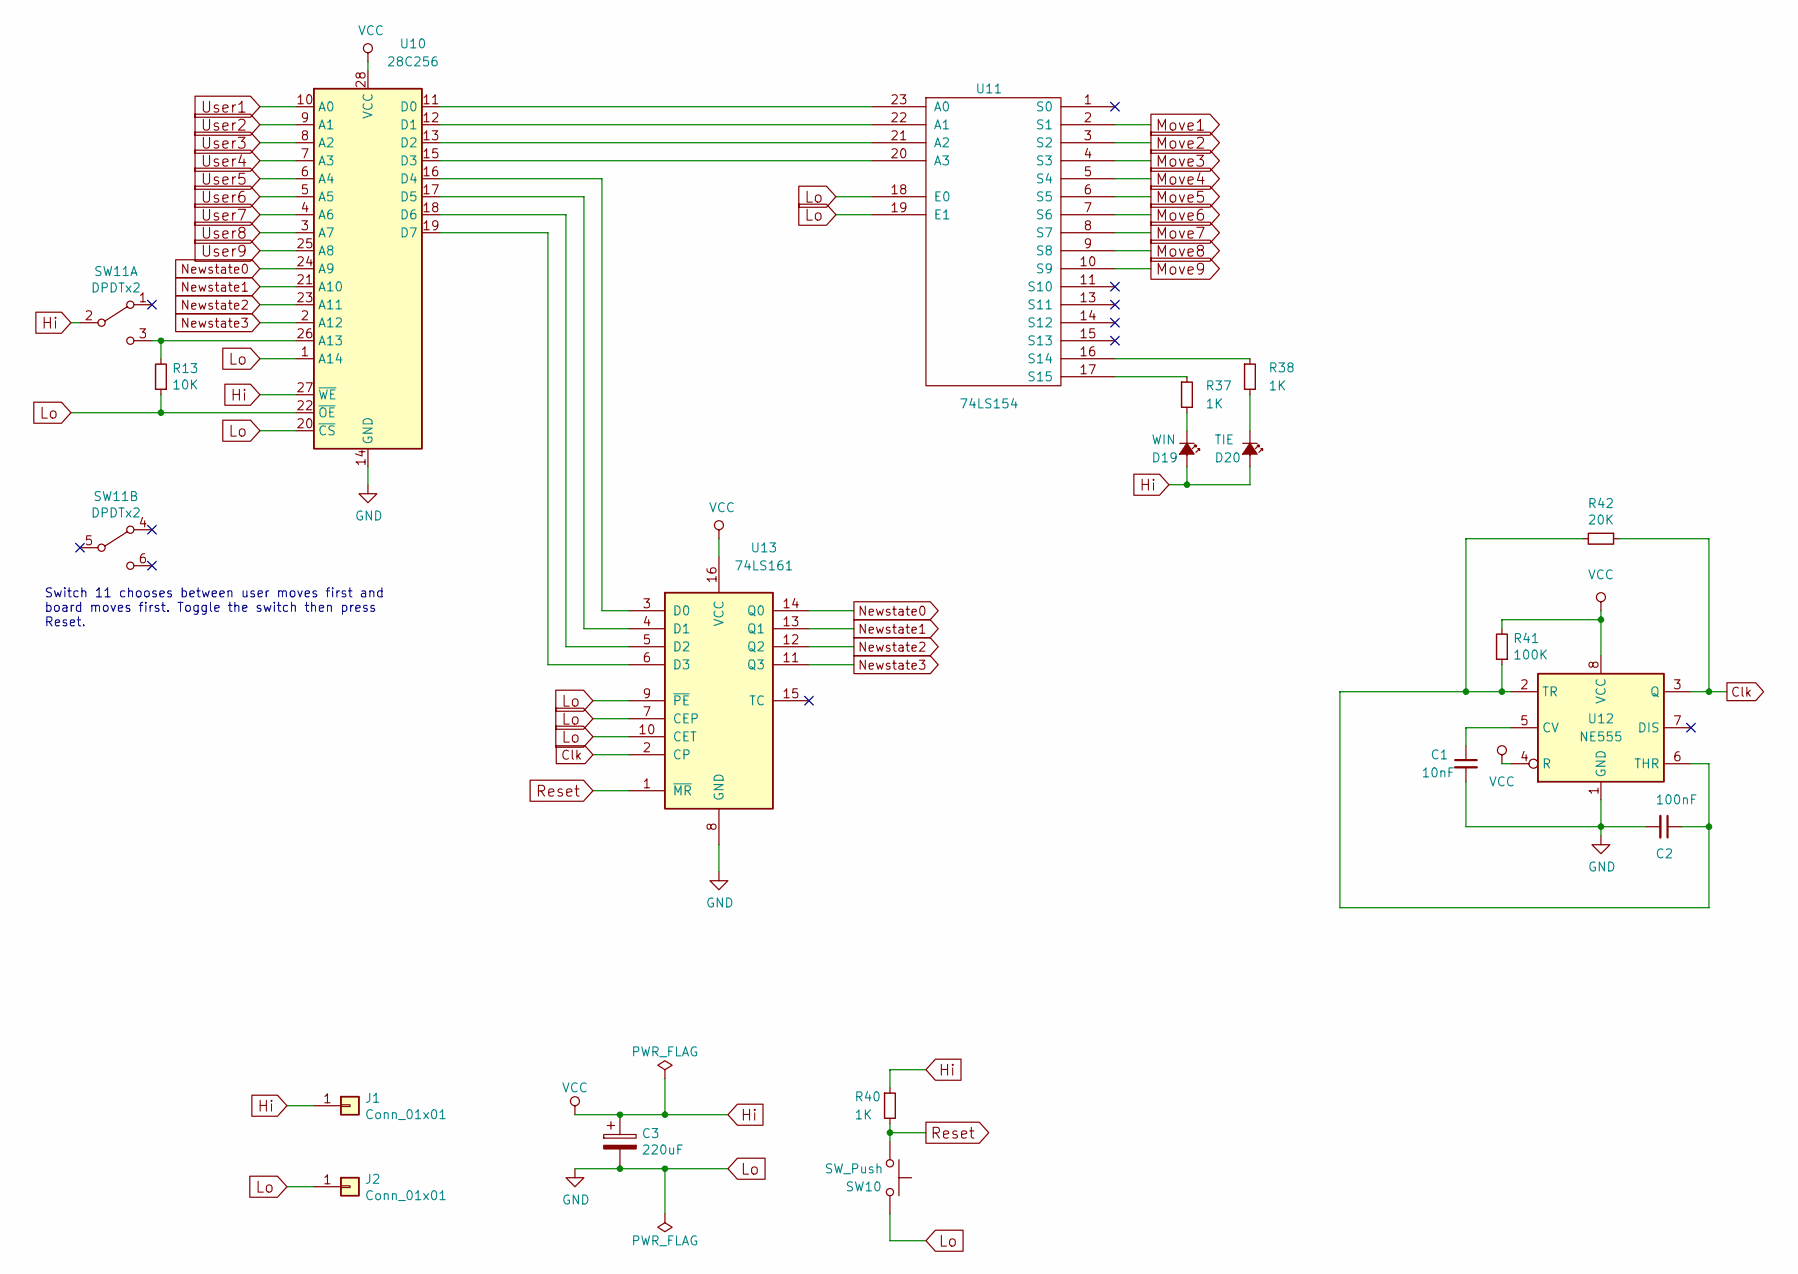
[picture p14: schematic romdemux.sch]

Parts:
C1: 10nF; C_Disc_D4.7mm_W2.5mm_P5.00mm
C2: 100nF; C_Disc_D4.7mm_W2.5mm_P5.00mm
C3: 220uF; CP_Radial_D10.0mm_P2.50mm
D19: WIN; LED_D3.0mm
D20: TIE; LED_D3.0mm
J1, J2: Conn_01x01; Pin_D1.0mm_L10.0mm
R13: 10K; R_Axial_DIN0207_L6.3mm_D2.5mm_P7.62mm_Horizontal
R37, R38, R40: 1K; R_Axial_DIN0207_L6.3mm_D2.5mm_P7.62mm_Horizontal
R41: 100K; R_Axial_DIN0207_L6.3mm_D2.5mm_P7.62mm_Horizontal
R42: 20K; R_Axial_DIN0207_L6.3mm_D2.5mm_P7.62mm_Horizontal
SW10: SW_Push; Push_E-Switch_KS01Q01
SW11: DPDTx2; DIP-6_W7.62mm
U10: 28C256; DIP-28_W15.24mm_Socket
U11: 74LS154; DIP-24_W7.62mm
U12: NE555; DIP-8_W7.62mm
U13: 74LS161; DIP-16_W7.62mm

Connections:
Clk: R42.1, U12.3 (Q), U13.2 (CP); also elsewhere on the board
Hi: C3.1, D19.2 (A), D20.2 (A), J1.1, R40.1, R41.2, SW11.2 (B), U10.27 (~WE), U10.28 (VCC), U11.24 (VCC), U12.4 (R), U12.8 (VCC), U13.16 (VCC); also elsewhere on the board
Lo: C1.2, C2.2, C3.2, J2.1, R13.1, SW10.2, U10.1 (A14), U10.14 (GND), U10.20 (~CS), U10.22 (~OE), U11.12 (GND), U11.18 (E0), U11.19 (E1), U12.1 (GND), U13.7 (CEP), U13.8 (GND), U13.9 (~PE), U13.10 (CET); also elsewhere on the board
Move1: U11.2 (S1); also elsewhere on the board
Move2: U11.3 (S2); also elsewhere on the board
Move3: U11.4 (S3); also elsewhere on the board
Move4: U11.5 (S4); also elsewhere on the board
Move5: U11.6 (S5); also elsewhere on the board
Move6: U11.7 (S6); also elsewhere on the board
Move7: U11.8 (S7); also elsewhere on the board
Move8: U11.9 (S8); also elsewhere on the board
Move9: U11.10 (S9); also elsewhere on the board
unnamed: C1.1, U12.5 (CV)
unnamed: C2.1, R41.1, R42.2, U12.2 (TR), U12.6 (THR)
unnamed: D19.1 (K), R37.2
unnamed: D20.1 (K), R38.2
unnamed: R13.2, SW11.3 (C), U10.26 (A13)
unnamed: R37.1, U11.17 (S15)
unnamed: R38.1, U11.16 (S14)
unnamed: U10.11 (D0), U11.23 (A0)
unnamed: U10.12 (D1), U11.22 (A1)
unnamed: U10.13 (D2), U11.21 (A2)
unnamed: U10.15 (D3), U11.20 (A3)
unnamed: U10.16 (D4), U13.3 (D0)
unnamed: U10.17 (D5), U13.4 (D1)
unnamed: U10.18 (D6), U13.5 (D2)
unnamed: U10.19 (D7), U13.6 (D3)
Newstate0: U10.24 (A9), U13.14 (Q0)
Newstate1: U10.21 (A10), U13.13 (Q1)
Newstate2: U10.23 (A11), U13.12 (Q2)
Newstate3: U10.2 (A12), U13.11 (Q3)
Reset: R40.2, SW10.1, U13.1 (~MR); also elsewhere on the board
User1: U10.10 (A0); also elsewhere on the board
User2: U10.9 (A1); also elsewhere on the board
User3: U10.8 (A2); also elsewhere on the board
User4: U10.7 (A3); also elsewhere on the board
User5: U10.6 (A4); also elsewhere on the board
User6: U10.5 (A5); also elsewhere on the board
User7: U10.4 (A6); also elsewhere on the board
User8: U10.3 (A7); also elsewhere on the board
User9: U10.25 (A8); also elsewhere on the board

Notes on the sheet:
Switch 11 chooses between user moves first and board moves first. Toggle the switch then press Reset.

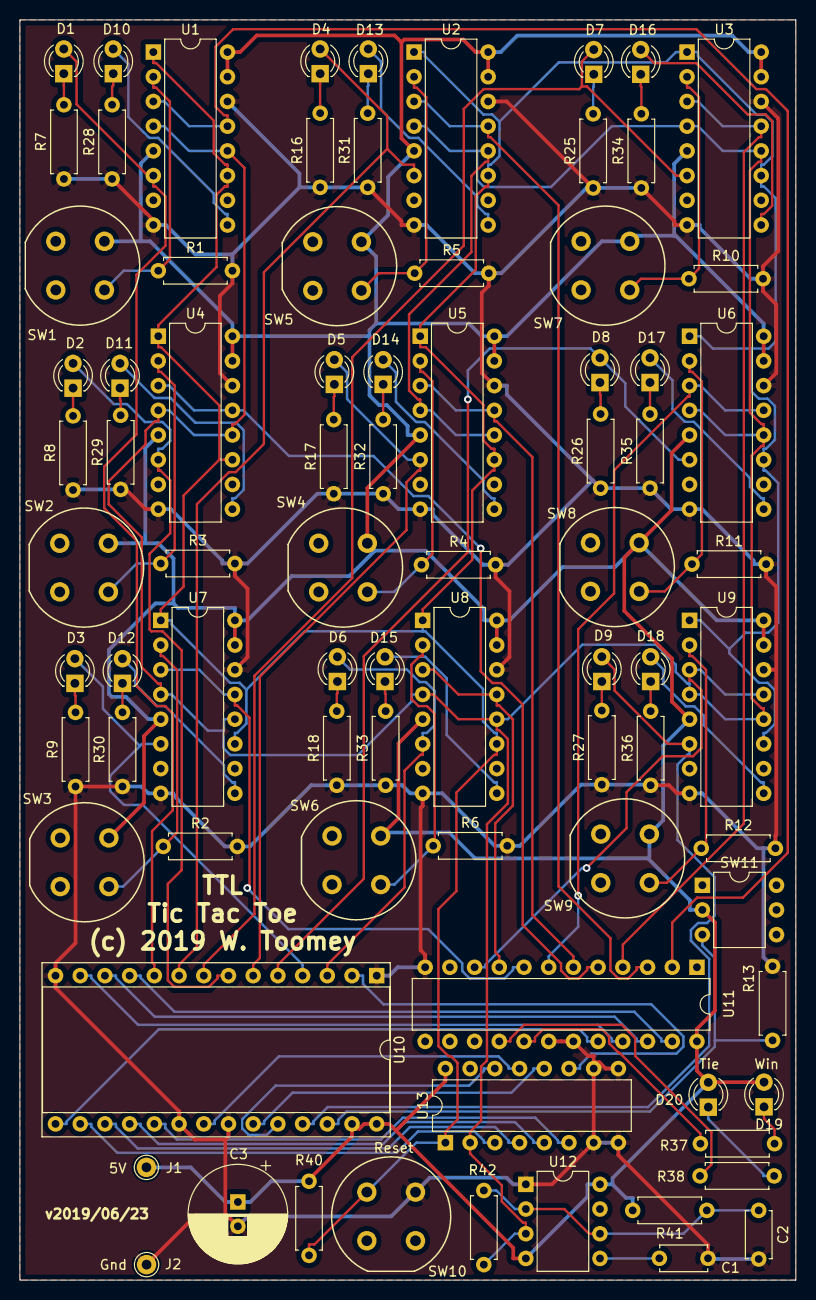
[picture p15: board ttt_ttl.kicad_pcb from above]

Board: 2 copper layers, 79.8 x 129.5 mm, 82 parts (0 on the bottom side), 77 nets.

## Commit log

2019-06-05 Added the Logisim circuit and the working ROM image for it
2019-06-05 More details of the circuit.
2019-06-05 I've made a start on an actual circuit and PCB for the game.
    [boardmoves.sch, romdemux.sch, ttt_ttl.kicad_pcb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]
2019-06-06 More work on the circuit and the PCB layout.
    [boardmoves.sch, ttt_ttl.kicad_pcb, usermoves.sch]
2019-06-11 I gave up on trying to use a smaller ROM.
    I've moved the LEDs in the Logisim version to a 3x3 grid in the
    top-right corner of the circuit.
2019-06-11 Added a BoM and a PDF schematic
    [bom.csv]
2019-06-11 Fixed up the reset line circuitry
    [romdemux.sch, ttt_ttl.kicad_pcb, usermoves.sch]
2019-06-12 Updated the schematic and PCB with the new flip-flip pinouts and footprints.
    [boardmoves.sch, romdemux.sch, ttt_ttl.kicad_pcb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]
2019-06-12 Updated the schematic PDF and the Readme.
2019-06-12 Updated the bill of materials.
    [bom.csv]
2019-06-12 Another BOM fix
    [bom.csv]
2019-06-12 Added a PCB image and moved all images to Figs/
2019-06-12 Fixed ROM part, was 27C020, should be 27C2001
    [bom.csv, romdemux.sch, ttt_ttl.kicad_pcb]
2019-06-16 Smaller 8Kx8 EEPROM is working
    I managed to get the code to generate a ROM file which uses a 4-bit board
    state plus the user's moves to look up the net board move and the next
    board state. I've redone the schematic, PCB and I've started on the
    documentation. I need to redraw the design diagram.
    [boardmoves.sch, romdemux.sch, ttt_ttl.kicad_pcb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]
2019-06-17 I bought different pushbuttons, so I updated the PCB design.
    [romdemux.sch, ttt_ttl.kicad_pcb, usermoves.sch]
2019-06-18 Small circuit change. Tie/win LEDs must connect to demux active low output.
    [romdemux.sch, ttt_ttl.kicad_pcb]
2019-06-18 Changed to horizontal resistors on PCB.
    This resulted in only two vias, so that's nice.
    [boardmoves.sch, bom.csv, romdemux.sch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]
2019-06-18 Updated the PCB image
2019-06-19 Did some more breadboard wiring, updated the journal.
2019-06-20 Edging closer to a full circuit on the breadboard.
2019-06-20 Fixed a wiring issue and the breadboard version works perfectly!
2019-06-23 Thanks to Ken Yap, I modified the project to optionally allow the board to move first.
    [bom.csv, romdemux.sch, ttt_ttl.kicad_pcb]
2019-06-23 Updated the PCB version number.
    [ttt_ttl.kicad_pcb]
2019-06-23 Updated the PDF of the schematic.
2019-06-28 My final journal entry with a PCB photo.
2019-06-28 Changed PCB link to real photo.

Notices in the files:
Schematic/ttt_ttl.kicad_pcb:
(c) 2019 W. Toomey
